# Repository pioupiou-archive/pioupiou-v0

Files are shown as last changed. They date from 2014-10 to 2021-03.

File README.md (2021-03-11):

pioupiou-v0
===========

Fichiers sources pour la balise Pioupiou version 0

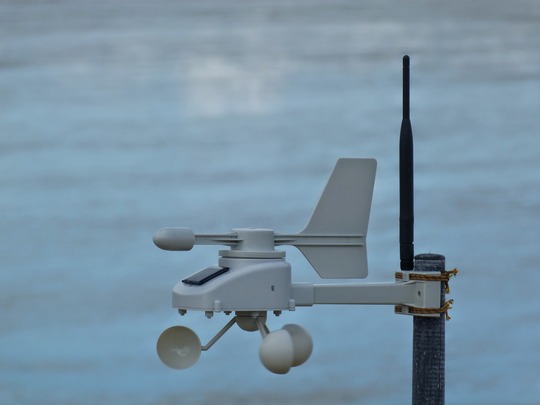
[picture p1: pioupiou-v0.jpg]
Pioupiou V0


Les fichiers de CAO (schéma et PCB) sont à utiliser avec le logiciel Kicad, gratuit (et Grenoblois !). Disponible pour Windows, Mac et Linux sur http://www.kicad-pcb.org/

Ce « brouillon » a été mis à la retraite après avoir rempli sa mission. Nous pouvons maintenant nous appuyer sur cette expérience pour mettre au point Pioupiou version 1. https://open.pioupiou.fr/Pioupiou_v1

## BUGS :
Il y a deux bugs à corriger sur cette version :
* Il faut enlever le plan de masse sous les connecteurs des batteries, sinon risque de court-circuit.
* Il faut ajouter une TVS ainsi qu'une self de 10nH en parallèle entre l'antenne et la masse. (protection électricité statique des orages)

## License

Copyright (c) 2015 Bac Plus Zéro SAS

Copyright (c) 2016 Altostratus SA

Copyright (c) 2021 OpenWindMap SCIC SA and contributors

**Permission is granted to anyone to use this Material for any purpose, including commercial applications, and to alter it and redistribute it freely, subject to the following restrictions:**

**ATTRIBUTION:** You must give appropriate credit, provide a link to the license, and indicate if changes were made. You may do so in any reasonable manner, but not in any way that suggests the licensor endorses you or your use.

**SHARE-ALIKE:** If you remix, transform, or build upon the Material, you must distribute your contributions under the same license as the original. You must include a copy of this License with every copy of this Material or modified version of this Material You distribute or otherwise make available.

**OBLIGATION TO SHARE WITHIN THE OPENWINDMAP NETWORK:** If you use this Material or a modified version of this Material to build a product that collects environmental data, this data must be published within the OpenWindMap network. You must not intentionally degrade the quality of the data, reduce the accuracy of its geolocation or delay its dissemination.

**OPEN-DATA:** If you use this Material or a modified version of this Material to build a product that collects environmental data, this data should be published under an Open-Data license. The chosen license must allow free reuse and redistribution, including from commercial entities and for commercial use. The choosen license must either be compliant with the [Open Definition](https://opendefinition.org/od/2.1/en/) or receive approval from OpenWindMap's board. You are allowed to offer a version of this data under any other license of your choice (including non-free licenses), as long as you also provide an identical version of this data under an Open-Data license as defined in this paragraph.

**DISCLAIMER OF WARRANTY/LIMITATION OF REMEDIES:** OpenWindMap and its contributors have no obligation to support this Material. OpenWindMap and its contributors are providing this Material "AS IS", with no express or implied warranties of any kind, including, but not limited to, any implied warranties of merchantability or fitness for any particular purpose or warranties against infringement of any proprietary rights of a third party.

**OpenWindMap and its contributors will not be liable for any consequential, incidental, or special damages, or any other relief, or for any claim by any third party, arising from your use of this Material.**

For the avoidance of doubt, OpenWindMap may offer this Material under separate terms or conditions or stop distributing this Material at any time; however, doing so will not terminate this License.

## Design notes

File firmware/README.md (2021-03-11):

Pioupiou_v0
===========

Fichiers sources pour le firmware balise Pioupiou v0.

A utiliser avec le SDK TD1208 de Telecom Design:
https://developers.insgroup.fr/cloud-on-chip/td1208/sdk.html

Ce code est un peu brouillon, mais il était là pour démontrer le concept.

Pour la licence, voir README.md à la racine de ce repository

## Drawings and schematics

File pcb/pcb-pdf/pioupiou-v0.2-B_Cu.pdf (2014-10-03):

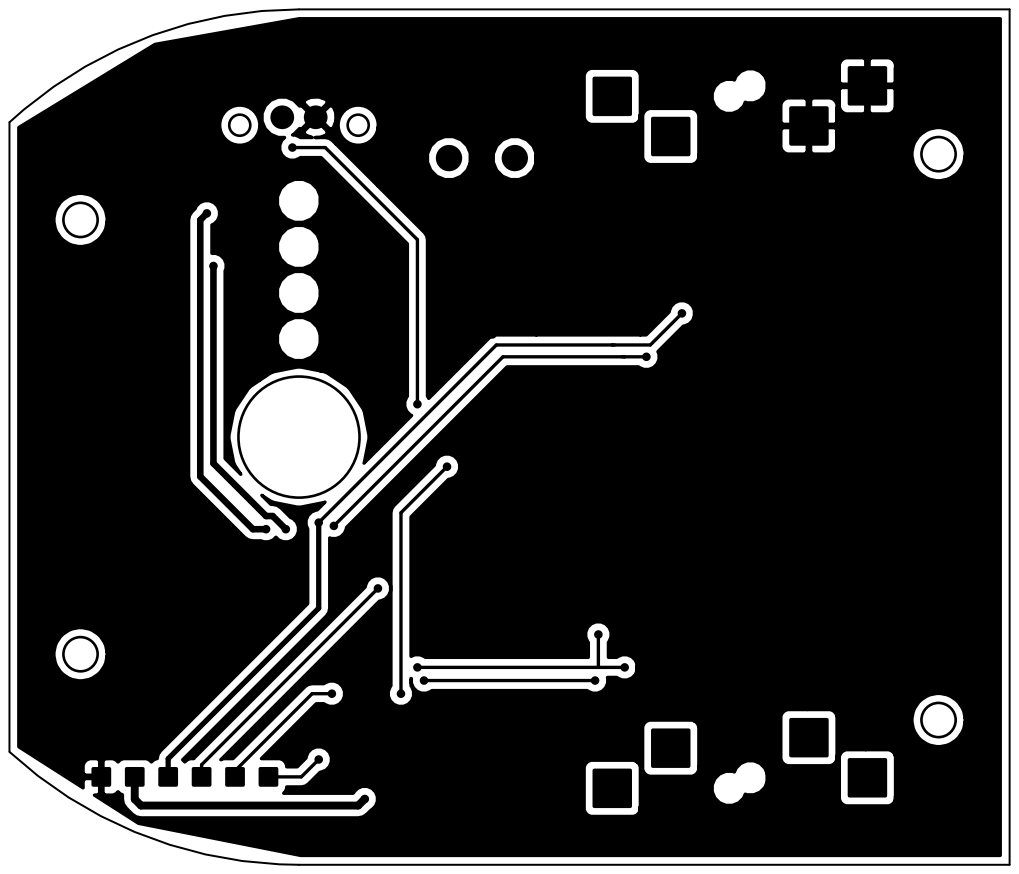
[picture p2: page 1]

Licence : https://open.pioupiou.fr/Licence
Open-Hardware
File: pcb.kicad_pcb Sheet: Nicolas BALDECK / Bac plus zéro SASU

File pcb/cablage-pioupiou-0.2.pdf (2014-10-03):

## Nomenclature

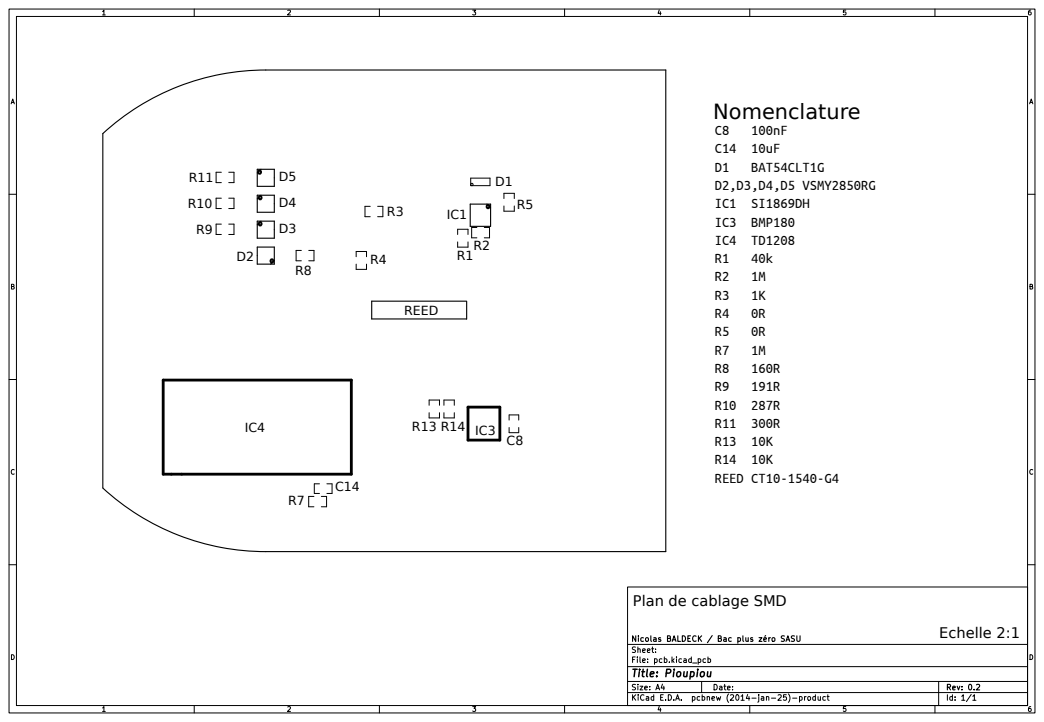
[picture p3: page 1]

Plan de cablage SMD

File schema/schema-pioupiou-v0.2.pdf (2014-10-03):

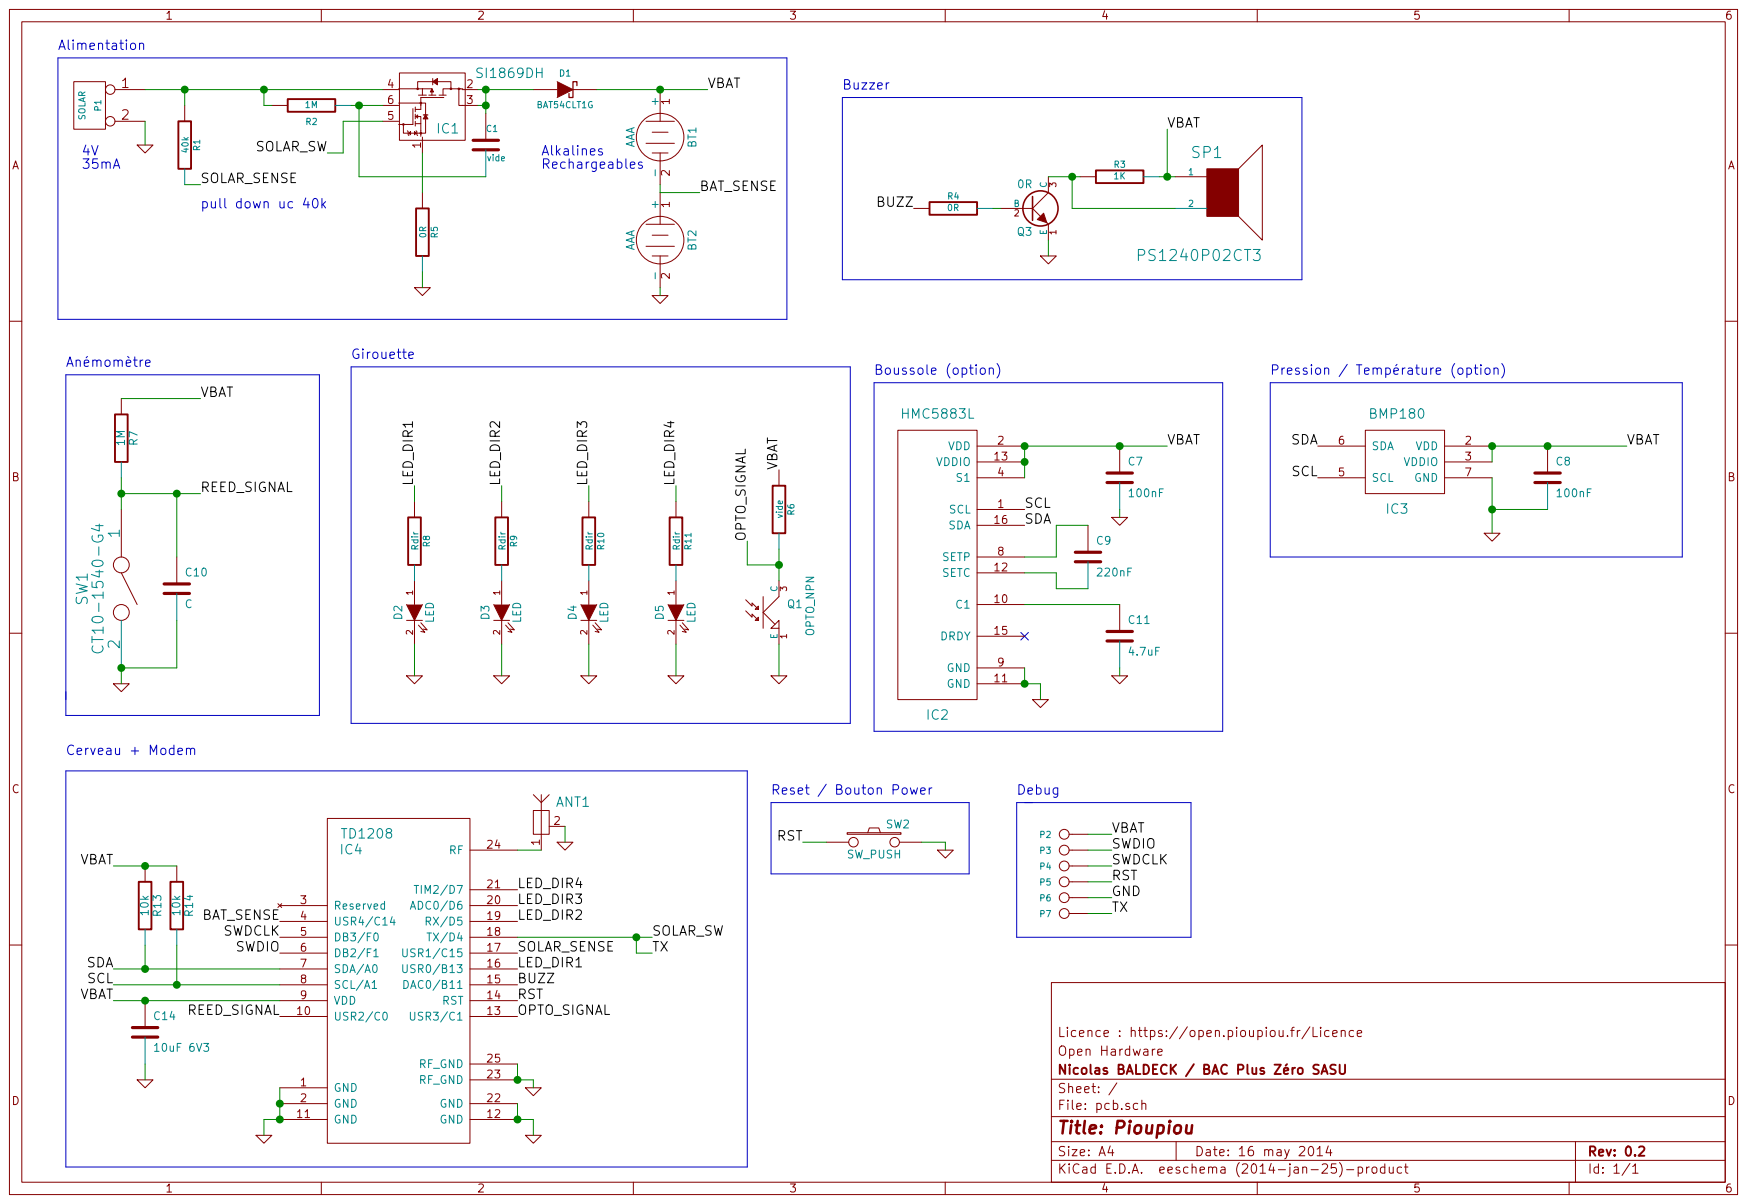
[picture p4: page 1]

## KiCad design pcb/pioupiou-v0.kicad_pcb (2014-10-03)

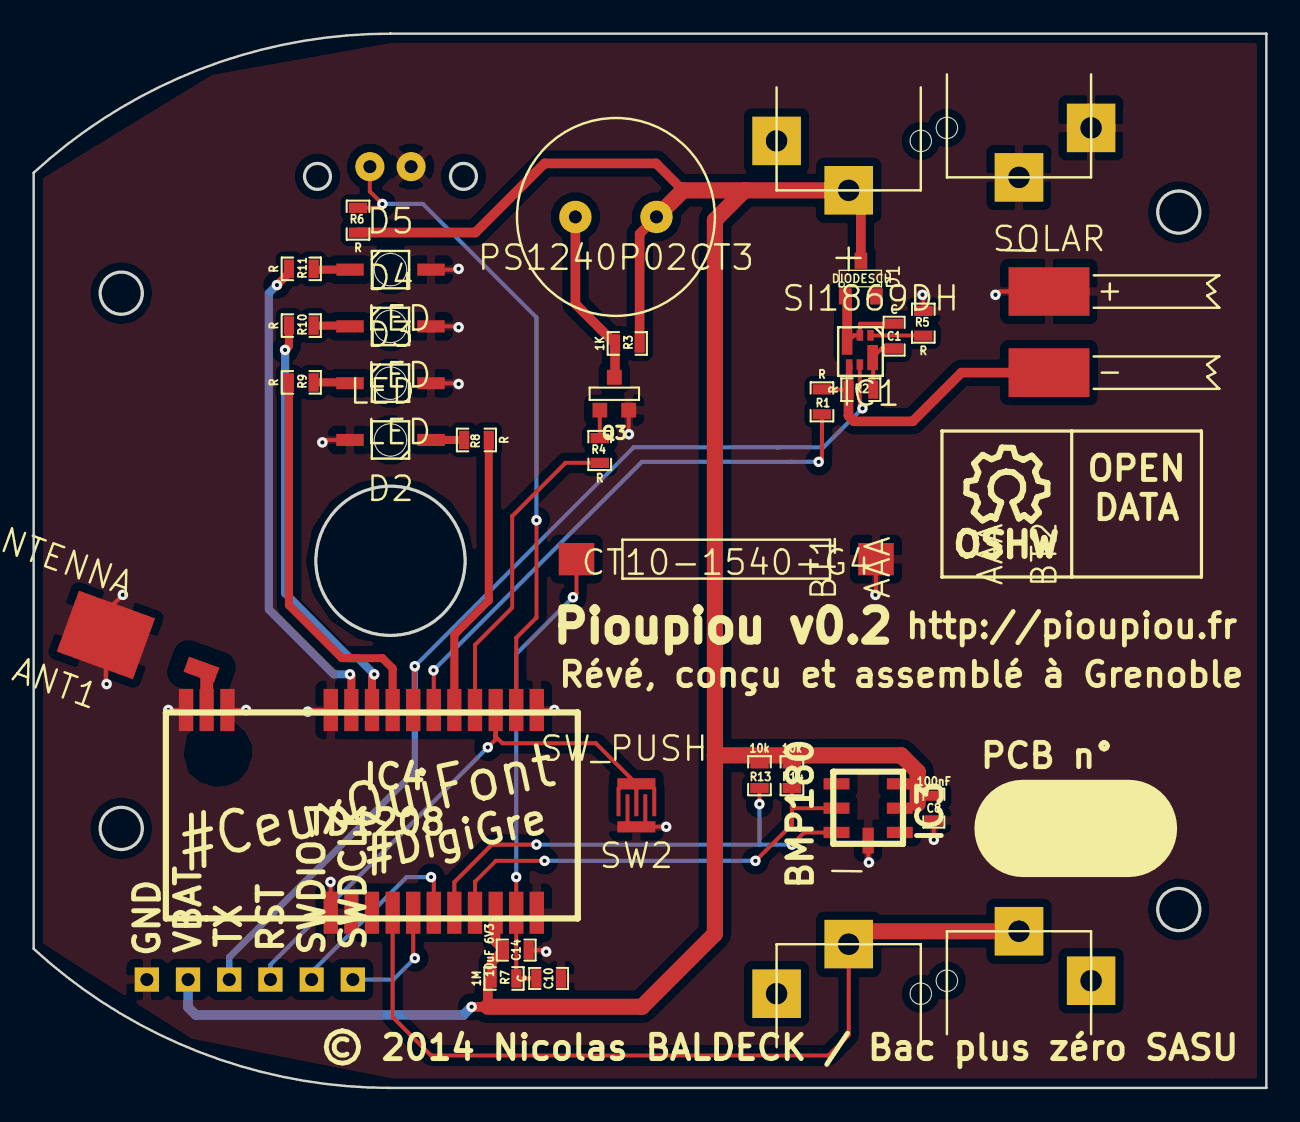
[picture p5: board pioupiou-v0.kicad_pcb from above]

Board: 2 copper layers, 76.0 x 65.0 mm, 41 parts (1 on the bottom side), 28 nets.

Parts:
ANT1: ANTENNA; RG178_SOLDER
BT1, BT2: AAA; AAA_KEYSTONE
C1, C10: C; SM0603_Capa
C8: 100nF; SM0603_Capa
C14: 10uF 6V3; SM0603_Capa
D1: DIODESCH; SOT23
D2, D3, D4, D5: LED; LED_2mm_GW
GND: CONN_1; Measurement_Point_Square-TH_Small
IC1: SI1869DH; Si1869DH
IC3: BMP180
IC4: TD1208
P1: SOLAR; SOLAR_WIRE
Q1: OPTO_NPN; PHOTOTRANS
Q3: NPN; SOT23EBC
R1, R2, R4, R5, R6, R8, R9, R10, R11: R; SM0603_Resistor
R3: 1K; SM0603_Resistor
R7: 1M; SM0603_Resistor
R13, R14: 10k; SM0603_Resistor
RST: CONN_1; Measurement_Point_Square-TH_Small
SP1: PS1240P02CT3
SW1: CT10-1540-G4
SW2: SW_PUSH; SW_CARBON
SWDCLK: CONN_1; Measurement_Point_Square-TH_Small
SWDIO: CONN_1; Measurement_Point_Square-TH_Small
SYM: Symbol_OSHW-Logo_SilkScreen_07Jul2012
TX: CONN_1; Measurement_Point_Square-TH_Small
VBAT: CONN_1; Measurement_Point_Square-TH_Small

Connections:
/BAT_SENSE: BT1.2, BT2.1, IC4.4
/BUZZ: IC4.15, R4.1
/LED_DIR1: IC4.16, R8.1
/LED_DIR2: IC4.19, R9.1
/LED_DIR3: IC4.20, R10.1
/LED_DIR4: IC4.21, R11.1
/OPTO_SIGNAL: IC4.13, Q1.3, R6.2
/REED_SIGNAL: C10.1, IC4.10, R7.2, SW1.1
/RST: IC4.14, RST.1, SW2.1
/SCL: IC3.5, IC4.8, R14.2
/SDA: IC3.6, IC4.7, R13.2
/SOLAR_SENSE: IC4.17, R1.2
/SOLAR_SW: IC1.5, IC4.18, TX.1
/SWDCLK: IC4.5, SWDCLK.1
/SWDIO: IC4.6, SWDIO.1
/VBAT: BT1.1, C8.1, C14.1, D1.3, IC3.2, IC3.3, IC4.9, R3.2, R6.1, R7.1, R13.1, R14.1, SP1.1, VBAT.1
GND: ANT1.2, BT2.2, C8.2, C10.2, C14.2, D2.2, D3.2, D4.2, D5.2, GND.1, IC3.7, IC4.1, IC4.2, IC4.11, IC4.12, IC4.22, IC4.23, IC4.25, P1.2, Q1.1, Q3.1, R5.2, SW1.2, SW2.2
unnamed: ANT1.1, IC4.24
unnamed: IC1.1, R5.1
unnamed: C1.2, IC1.6, R2.2
unnamed: IC1.4, P1.1, R1.1, R2.1
unnamed: C1.1, D1.1, IC1.2, IC1.3
unnamed: Q3.2, R4.2
unnamed: Q3.3, R3.1, SP1.2
unnamed: D2.1, R8.2
unnamed: D5.1, R11.2
unnamed: D4.1, R10.2
unnamed: D3.1, R9.2

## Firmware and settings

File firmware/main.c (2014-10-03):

#include <em_cmu.h>
#include <em_leuart.h>

#include <td_core.h>
#include <td_uart.h>
#include <td_printf.h>
#include <td_watchdog.h>

#include "power.h"
#include "anemo.h"
#include "girouette.h"
#include "pression.h"
#include "reports.h"


/* This file declare all "dynamic" library data. It should be last included file
 * Standard size value can be override before including this file
 */
#define CHIP_TD1208
#define TD_SENSOR_USE_CODE 0
#define TD_GEOLOC_USE_CODE 0
#define PRODUCT_BOOTLOADER_SKIP 1
#include <td_config.h>

void SERIAL_DEBUG_Putc(void * p, char c) {
	LEUART_Tx(LEUART0, c);
}
void SERIAL_DEBUG_Void(void * p) {}
void* SERIAL_DEBUG_VoidVoid() {}


void SERIAL_DEBUG_Init() {

	CMU_ClockSelectSet(cmuClock_LFA, cmuSelect_LFXO);
	CMU_ClockSelectSet(cmuClock_LFB, cmuSelect_LFXO);
	CMU_ClockEnable(cmuClock_CORELE, true);
	CMU_ClockEnable( cmuClock_LEUART0, true );

	LEUART_Init_TypeDef leuart0Init =
	{
	  .enable   = leuartEnableTx,       /* Activate data reception on LEUn_TX pin. */
	  .refFreq  = 0,                    /* Inherit the clock frequenzy from the LEUART clock source */
	  .baudrate = 9600,                 /* Baudrate = 9600 bps */
	  .databits = leuartDatabits8,      /* Each LEUART frame containes 8 databits */
	  .parity   = leuartNoParity,       /* No parity bits in use */
	  .stopbits = leuartStopbits2,      /* Setting the number of stop bits in a frame to 2 bitperiods */
	};

	//LEUART_Reset(LEUART0);
	LEUART_Init(LEUART0, &leuart0Init);

	LEUART0->ROUTE = LEUART_ROUTE_TXPEN | LEUART_ROUTE_LOCATION_LOC0;

	GPIO_PinModeSet(gpioPortD,                /* GPIO port */
				  4,                        /* GPIO port number */
				  gpioModePushPull,         /* Pin mode is set to push pull */
				  1);

	init_printf(SERIAL_DEBUG_VoidVoid(), SERIAL_DEBUG_Putc, SERIAL_DEBUG_Void,SERIAL_DEBUG_Void);
}


void TD_USER_Setup(void)
{


	PP_POWER_Init();
	PP_REPORTS_Init();
	PP_GIROUETTE_Init();
	PP_PRESSION_Init();
	PP_ANEMO_Init();

	//SERIAL_DEBUG_Init();


	//tfp_printf("Start test\r\n");

	//PP_GIROUETTE_Test ();

	//PP_PRESSION_Init();
	//PP_PRESSION_Read();

	//while (true) {
	//	tfp_printf("%d\n", PP_GIROUETTE_Read());
	//	TD_RTC_Delay(T200MS);
	//}






	/*while (true) {
		GPIO_PinOutToggle(DAC0_PORT, DAC0_BIT);
		int i;
		for(i=0; i<1000; i++) {}
	}*/


	/*PP_REPORTS_Init();

	PP_ANEMO_Init();
	PP_I2C_Init();
	PP_Boussole_Init();

	while (true) {

		uint8_t data[6];
		PP_I2C_Read6bytesReg(HMC_ADDR, HMC_DATA_REG_X_MSB, data);

		int x = (int16_t)((data[0] << 8) | data[1]);
		int y = (int16_t)((data[2] << 8) | data[3]);
		int z = (int16_t)((data[4] << 8) | data[5]);
		int dir = atan2(y, x)*180./3.14;

		tfp_printf("%d\t%d\t%d\t%d\n", x, y, z, dir);

		TD_RTC_Delay(67*32768/1000); // wait 67 ms

	}*/

}

void TD_USER_Loop(void)
{
	//tfp_printf("Loop %d %d\r\n", RTC_CounterGet()/32768, TD_RTC_GetOverflowCounter());
}

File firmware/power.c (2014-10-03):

/*
 * power.c
 *
 *  Created on: 2 juin 2014
 *      Author: nicolas
 */
#include "power.h"

bool lowBatMode = false;

void PP_POWER_ChargeInit () {
	GPIO_PinModeSet(SOLAR_SWITCH_PORT, SOLAR_SWITCH_PIN, gpioModePushPull, 0);
}

void PP_POWER_SolarSenseInit () {
	GPIO_PinModeSet(SOLAR_SENSE_PORT, SOLAR_SENSE_PIN, gpioModeDisabled, 0);
}

void PP_POWER_BatterySenseInit () {
	GPIO_PinModeSet(BATTERY_SENSE_PORT, BATTERY_SENSE_PIN, gpioModeInput, 0);
}

void PP_POWER_BeepInit() {
	GPIO_PinModeSet(BEEP_PORT, BEEP_PIN, gpioModePushPull, 1);
}

void PP_POWER_Beep(beepModeTypedef beepMode) {

	int i,j,k;

	switch (beepMode) {

		case BEEP_STARTUP:
			for (i=0; i<1118; i++) {
				GPIO_PinOutToggle(BEEP_PORT, BEEP_PIN);
				for(j=0; j<313; j++) {}
			}
			for (i=0; i<1400; i++) {
					GPIO_PinOutToggle(BEEP_PORT, BEEP_PIN);
					int j;
					for(j=0; j<250; j++) {}
			}
			for (i=0; i<1659; i++) {
				GPIO_PinOutToggle(BEEP_PORT, BEEP_PIN);
				int j;
				for(j=0; j<211; j++) {}
			}
			break;

		case BEEP_SHUTDOWN:
			for (i=0; i<1659; i++) {
				GPIO_PinOutToggle(BEEP_PORT, BEEP_PIN);
				int j;
				for(j=0; j<211; j++) {}
			}
			for (i=0; i<1400; i++) {
					GPIO_PinOutToggle(BEEP_PORT, BEEP_PIN);
					int j;
					for(j=0; j<250; j++) {}
			}
			for (i=0; i<1118; i++) {
				GPIO_PinOutToggle(BEEP_PORT, BEEP_PIN);
				for(j=0; j<313; j++) {}
			}
			break;

		case BEEP_LOWBAT:
			for (k=0; k<5; k++) {
				for (i=0; i<800; i++) {
					GPIO_PinOutToggle(BEEP_PORT, BEEP_PIN);
					for(j=0; j<211; j++) {}
				}
				for (i=0; i<1E4; i++) {}
			}
			break;

	}

	GPIO_PinOutSet(BEEP_PORT, BEEP_PIN);
}

void PP_POWER_DiagMessage(uint8_t messageType) {
	uint8_t sigfoxFrame[2] = {messageType, TD_MEASURE_VoltageTemperature(false)};
	TD_SIGFOX_Send(sigfoxFrame, 2,2);
}

void PP_POWER_ChargeDisable () {
	GPIO_PinOutClear(SOLAR_SWITCH_PORT, SOLAR_SWITCH_PIN);
}
void PP_POWER_ChargeEnable () {
	GPIO_PinOutSet(SOLAR_SWITCH_PORT, SOLAR_SWITCH_PIN);
}
bool PP_POWER_IsCharging () {
	return GPIO_PinOutGet(SOLAR_SWITCH_PORT, SOLAR_SWITCH_PIN);
}

bool batteryIsCharged;

void VCMP_IRQHandler() {
	if (VCMP->IF & VCMP_IF_EDGE) {
	    batteryIsCharged = true;
	    VCMP_IntClear(VCMP_IFC_EDGE);
	  }
}

void PP_POWER_SleepUntilCharged () {
	PP_POWER_Beep(BEEP_LOWBAT);

	PP_POWER_DiagMessage(DIAG_MSG_POWERSLEEP);

	// wake quand batterie chargée

	VCMP_Init_TypeDef init = VCMP_INIT_DEFAULT;

	init.halfBias     = 1;
	init.biasProg     = 7;
	init.irqFalling   = 0;
	init.irqRising    = 1;
	init.warmup       = vcmpWarmTime4Cycles;
	init.hyst         = vcmpHyst20mV;
	init.lowPowerRef  = 1;
	init.triggerLevel = VCMP_VoltageToLevel((float)BATTERY_WAKECHARGED_LIMIT/500.);

	CMU_ClockEnable(cmuClock_VCMP, true);

	VCMP_Init(&init);

	NVIC_EnableIRQ(VCMP_IRQn);
	VCMP_IntEnable(VCMP_IEN_EDGE);

	VCMP_Enable();
	while (!VCMP_Ready()) ;

	PP_POWER_ChargeEnable();

	batteryIsCharged = false;

	while (batteryIsCharged == false) {
		EMU_EnterEM3(true);
	}

	PP_POWER_ChargeDisable();

	VCMP_Disable();
	CMU_ClockEnable(cmuClock_VCMP, false);

	PP_POWER_DiagMessage(DIAG_MSG_POWERWAKE);

}

void PP_POWER_LowBatModeSet () {
	lowBatMode = true;
}
void PP_POWER_LowBatModeClear () {
	lowBatMode = false;
}
bool PP_POWER_LowBatModeGet () {
	return lowBatMode;
}

void PP_POWER_CheckBattery () {

	int32_t voltage; // millivolts

	voltage = TD_MEASURE_VoltageTemperatureExtended(false);

	if (voltage >= BATTERY_CHARGE_LIMIT*2) {
		PP_POWER_ChargeDisable();
	} else if (voltage <= BATTERY_HARD_LIMIT*2) {
		PP_POWER_SleepUntilCharged();
		PP_POWER_Beep(BEEP_STARTUP);
	} else {
		PP_POWER_ChargeEnable();
		if (voltage  <= BATTERY_SOFT_LIMIT*2) {
			PP_POWER_LowBatModeSet();
		} else {
			PP_POWER_LowBatModeClear();
		}
	}

	//TODO : prendre en compte la mesure intermediaire

}

void PP_POWER_Shutdown () {
	// peut-être reveillé uniquement par un reset

	// TODO: envoyer un message ?

	PP_POWER_ChargeDisable();

	RMU_ResetCauseClear();

	EMU_EnterEM4();
	//TODO: voir si EM4 conserve l'état des pins.
	// sinon faire un while (1) { EMU_EnterEM3(false) };

}


bool PP_POWER_IsUnderSunlight () {

	bool wasCharging = PP_POWER_IsCharging();
	PP_POWER_ChargeDisable();

	CMU_ClockEnable(cmuClock_ACMP1, true);

	ACMP_Init_TypeDef init = ACMP_INIT_DEFAULT;
	init.fullBias                 = 0;
	init.halfBias                 = 1;
	init.biasProg                 = 12;
	init.warmTime                 = acmpWarmTime512;
	init.hysteresisLevel          = acmpHysteresisLevel5;
	init.lowPowerReferenceEnabled = 0;
	init.vddLevel                 = 18; //  0,3x VDD
	init.interruptOnFallingEdge   = 0;
	init.interruptOnRisingEdge    = 0;
	init.inactiveValue            = 0;

	ACMP_Init(ACMP1, &init);
	ACMP_ChannelSet(ACMP1, acmpChannelVDD, acmpChannel7);

	// pull-down
	GPIO_PinModeSet(SOLAR_SENSE_PORT, SOLAR_SENSE_PIN, gpioModeInputPull, 0);

	/* Wait for warmup */
	while (!(ACMP1->STATUS & ACMP_STATUS_ACMPACT)) ;

	bool isUnderSunlight = (int) ((ACMP1->STATUS & ACMP_STATUS_ACMPOUT) >> _ACMP_STATUS_ACMPOUT_SHIFT);

	// pull-up
	GPIO_PinModeSet(SOLAR_SENSE_PORT, SOLAR_SENSE_PIN, gpioModeDisabled, 0);

	ACMP_Reset(ACMP1);
	CMU_ClockEnable(cmuClock_ACMP1, false);

	if (wasCharging) PP_POWER_ChargeEnable();

	return isUnderSunlight;
}

void PP_POWER_Scheduler(uint32_t arg, uint8_t repetition) {
	TD_WATCHDOG_Feed();
	PP_POWER_CheckBattery();
}

void PP_POWER_Init () {

	uint32_t resetCause = RMU_ResetCauseGet();
	RMU_ResetCauseClear();

	PP_POWER_BatterySenseInit();
	PP_POWER_SolarSenseInit();
	PP_POWER_ChargeInit();
	PP_POWER_BeepInit();

	TD_WATCHDOG_Init(32);

	PP_POWER_CheckBattery();
	TD_WATCHDOG_Enable(true, false);

	//TODO/BUG on a RMU_RSTCAUSE_BODUNREGRST quand on sort de EM4
	if ((resetCause & RMU_RSTCAUSE_EXTRST) == RMU_RSTCAUSE_EXTRST) {
		if (!PP_POWER_IsUnderSunlight()) {
			PP_POWER_Beep(BEEP_SHUTDOWN);
			PP_POWER_DiagMessage(DIAG_MSG_POWEROFF);
			PP_POWER_Shutdown();
		}
	}

	PP_POWER_Beep(BEEP_STARTUP);

	TD_RTC_Delay(T5S);
	PP_POWER_DiagMessage(DIAG_MSG_POWERON);

	TD_SCHEDULER_Append(BATTERY_CHECK_PERIOD, 0, 0, TD_SCHEDULER_INFINITE, PP_POWER_Scheduler, 0);

}

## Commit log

2014-10-03 Upload vers github
    [modelisation panneau.ods, pinout_efm32.ods, pioupiou-v0.kicad_pcb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]
2014-10-03 liste des bugs

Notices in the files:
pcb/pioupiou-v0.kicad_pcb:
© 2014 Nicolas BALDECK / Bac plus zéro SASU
